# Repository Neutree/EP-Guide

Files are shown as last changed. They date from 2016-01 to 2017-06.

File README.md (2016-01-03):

EP-Guide
=========================
------Easy Parking Guide 智能车库引导系统
-------------------------

# 功能描述

* 可进行车库内车辆的定位(基于RFID)
* 进库时车库会自动寻找最佳位置，用灯光对用户进行引导停车
* 管理员使用web端进行管理
* 用户使用移动app进行查看修改车辆信息、接收提醒、分享信息等
* 家人功能，能够将停车信息贡献给家人，在回家停车时通过app告知家人

###### 管理员专有
* 设置车库布局和传感器布局（画图的方式画出布局，然后将传感器节点（RFID）拖动到相应位置）
* 查看车库内每个车位的停泊信息（是否停泊、如果是可以查看该车位的个人信息）
* 设置车位价格信息
* 设置用户个人信息

###### 用户
* 停车(停车时车库会进行泊车引导，让找车位更简单)
* 查看、修改自己的车辆信息
* 查看自己的车在车库的状态
* 预约车位功能（提前预定车位，保证到达时有车位）
* 家人功能，能够将停车信息贡献给家人，在回家停车时通过app告知家人

# 业务流程图

* 见[流程图](https://github.com/Neutree/EP-Guide/blob/master/Doc/Visio-EP-Guide场景功能流程图.pdf)

# 实现说明

###### 感知控制层
  * MCU：采用stm32f105/107系列
  * 语言：C++
  * 外设：LED、蜂鸣器、RFID阅读器和标签（实验时使用高频，但部署时使用超高频）、wifi模块（esp8266）
  * IDE：Eclipse
  * 电路：Altium Designer

###### 服务器
  * 语言：java
  * IDE：Eclipse
  * 框架：ssh

###### 客户端
* 语言：java
* 系统：Android
* IDE：Android Studio
* 框架模式：MVC
* API：Target:23 Min:15

# 托管地址

[Github->EP-Guide](https://github.com/Neutree/EP-Guide)

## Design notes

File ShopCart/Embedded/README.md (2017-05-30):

[STM32f103 Peripherals Driver Lib](https://github.com/Neutree/STM32f103DriverLib)
======

To make program on STM32 more easier, we packet every peripheral and module as a C++ class, mask operation steps instead of function-oriented interface.

> eg: How to use USART to send data
```cpp
# include "USART.h"
USART com(1,115200);
void main()
{
    com<<"test string\r\n";
}
```

_ _ _
_ _ _
# 如何使用

1. windows上安装keil MDK 5
2. 克隆(推荐)或者下载项目到本地目录,复制一个副本
```
git clone https://github.com/Neutree/STM32f103DriverLib.git
```
3. 打开/template文件夹，该文件夹下面会有相应IDE的工程模板，直接打开运行即可（onchip表示只有STM32片上驱动，offchip表示有一些常用模块的驱动）
4. 需要关心的文件主要在工程的app文件夹下，有三个文件，Main.cpp,Configuration.h,UserInterrupt.cpp.分别为主函数所在、配置使用哪些资源，中断用户程序。
  * 首先检查Configuration.h中需要使用的资源是否取消注释了，不需要使用的资源是否注释了
  * 然后看Main.cpp中硬件定义及其参数,每个外设驱动都有一个文件，具体每个外设驱动的使用请看其头文件。

# 规范
## 文件编码格式
UTF-8 without signature
> keil->edit->configuration->editor->encoding
 
## 目录规范

`lib`：驱动库目录
> `lib/math/`:外设会用到的算法库

> `lib/onchip/`:片上外设驱动
>> `lib/onchip/驱动名`:驱动接口的定义和对驱动的实现

> `lib/offchip/`:片外模块驱动

>> `lib/offchip/驱动名`:驱动接口的定义和对驱动的实现

`example`:驱动库demo，每个驱动一个文件夹,每个芯片一个文件夹
> `example/onchip/驱动名`：具体某个芯片的模块驱动

> `example/offchip/驱动名`：具体某个外围模块驱动

`template`：工程模板，每个IDE或者编译器一个文件夹，下面有特定芯片型号文件夹

`tool`:工具，如删除工程中间文件批处理文件

# 驱动简介

## 片上外设驱动
* **Interrupt**：片上外设中断管理，所有的中断相关的逻辑都在这里
* **GPIO**：通用IO驱动，包括基本IO配置与设置引脚和读取引脚状态
* **USART**：串口驱动，包括了串口1到串口4的驱动，发送可使用DMA，接收使用中断方式，每个串口使用单独的FIFO
* **ADC**：ADC驱动
* **I2C**：I2C驱动，包含了中断方式和DMA方式
* **PWM**：PWM驱动
* **Timer**：定时器驱动
* **TaskManager**：使用systick作为时基，可用来获取系统时间戳、延时（包含软件延时）和定时调用函数
* **Capture**：输入捕获，包括了定时器捕获和外部中断捕获
* **Flash**：STM32内部Flash相关操作，包括对Flash的读写

## 片外模块驱动
* **LED**：基于GPIO和PWM对LED的相关操作，包括开、关、闪烁等
* **esp8266**：esp8266是串口WIFI模块，基于USART对esp8266的相关操作，其中包括了驱动文件（esp8266.cpp）和应用层文件(SockeEsp8266.cpp),应用层文件是使用socket的接口进行通信的实现
* **GPS**：使用USART对GPS模块的驱动
* **HMC5883L**：磁力计，基于I2C通信的HMC5883L的驱动
* **StepMotor**：步进电机驱动，基于GPIO进行控制
* **MPU6050**：6轴惯导驱动，包括了角速度、加速度的读取
* **RemoteControl**:RC遥控器驱动，包含了PWM输入捕获和PPM输入捕获，包括了中断方式和定时器输入捕获方式
* **~~Ultrasonic~~** ~~：超声波驱动，包括了systick版本和定时器版本~~

## 代码风格
看[这里](https://github.com/neutree/simple-code-conventions)

# 贡献者
[AllenWang](https://github.com/afshare)

Danyuanhong

[infiniteYuan](https://github.com/InfiniteYuan1)

[lissettecarlr](https://github.com/lissettecarlr)

[neucrack](http://neucrack.com)

[xz1996](http://git.oschina.net/xz1996)

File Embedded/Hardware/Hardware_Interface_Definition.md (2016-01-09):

硬件外围设备接口定义
=========

# RFID（MFRC522）
* USART2
| 外设引脚名| 引脚编号 |
|---|---|
|TX2(外设RX) | PA2 |
|RX2（外设TX）| PA3 |

* SPI1
| 外设引脚名| 引脚编号 |
|---|---|
|NSS(CSN) | PA4 |
|SCK | PA5 |
|MISO（接收端）（外设MISO）|PA6|
|MOSI（发送端）（外设MOSI）|PA7|

# WIFI
* USART1
| 外设引脚名| 引脚编号 |
|---|---|
|TX1(外设RX) | PA9 |
|RX1（外设TX）| PA10 |

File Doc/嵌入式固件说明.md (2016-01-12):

EP-Guide嵌入式固件说明（V1.5）
=======
# 使用步骤及工作流程说明
1. 车库主控、车位节点、服务安装、部署
2. 开启服务器
3. 管理员现在管理系统（服务器端）进行设置节点数量以及添加MAC地址
4. 主控开机，上电两个灯闪烁一下，然后进行系统初始化、连接wifi等操作，直到交替闪烁表示初始化完毕。<br/>然后双闪表示登录服务器成功，闪4下表示登录服务器失败（如果在后面掉线了也是如此）;红灯双闪表示rfid连接有问题检测到车辆
5. 车位节点开机
6. 主控对所有连接进来了的节点进行轮询，向服务器请求添加节点，添加成功（根据管理员是否将MAC地址加入白名单）后将IP地址与MAC地址进行绑定；如果已经存在了的节点的IP地址有变化，重新设置绑定的IP值
7. 主控定时进行轮询，发现车位状态更改便向服务器报送
8. 当门禁（暂时由主控担任）检测到有车来临时，向服务器请求车位和到达该车位的路径（由车位组成），然后通知节点进行引导（灯光提示），当车在车位（不一定是系统指定的，可以由用户喜好自己选）停下后，主控在轮询中检测到，向服务器报告车位状态的改变，并向节点发送完成引导的消息，然后节点完成引导（灯光恢复正常，绿灯亮表示空闲，红灯亮表示已被占用或者已经被预约）
9. 当汽车离去时，车位检测到状态改变，在主控轮询的时候发送消息给主控，然后主控将消息传递给服务器

# 车库主控
* WIFI为AP+Station模式，作为车库其它节点的AP，同时联网，与服务器交互
  * AP名称：EP-Guide    (WIFI.cpp中可以修改)
  * AP密码：1208077207  (WIFI.cpp中可以修改)
  * AP IP：192.168.4.1                  (WIFI.cpp中可以修改)
  * AP端口：345
  * AP 网关：192.168.4.1  与主控的IP要相同 (WIFI.cpp中可以修改)

  * 作为Station连接的AP名：ICanHearYou
  * 密码：1208077207
  * MAC：12:08:07:72:07:01
* 由于WIFI耗用时间久，RFID扫描（轮询）又对时间要求高，所以要在程序上保证RFID能正确执行
* 对车位节点进行轮询来实现检测车位信息

# 车位节点

* 被动接收主控的轮询
* 既是客户端，也开启TCP服务器，监听来自主控的轮询
* 使用端口号：345 （即节点建立端口号为345的TCP服务）

# 主控与节点之间的通信

#### 节点-->主控
* 节点被动，响应主控的请求

#### 主控-->节点
* 由于主控不知道具体哪个IP对应哪个车位，因此需要将IP与节点MAC绑定
  * 在主控向节点请求状态信息时，在节点返回MAC地址+状态数据后，将IP与MAC进行绑定
* 主控定时向节点请求状态信息

#### 协议
**一）、消息帧定义**

| 传输层 |||| 业务层 |||
|---|---|
| 消息头 | 消息ID | 节点Mac地址 | 消息体长度 | 命令字 | 消息体 | 校验字 |
| gMsgHead | gMsgID | gGtwMac | gMsgLen | bMsgCmd | bMsgBody | bMsgVrf |
| 2Byte | 2Byte | 6Byte | 2Byte | 2Byte | nByte | 1Byte |

**二）、命令字定义**

| 命令编号 | 命令描述 | 命令字 | 命令编码 | 传输方向 |
|---|---|
| 1 | 主控向节点请求状态信息 | cReqStatus | 0x0201 | 主控-节点 |
| 2 | 节点响应主控状态信息请求 | cAckStatus | 0x0901 | 节点-主控 |
| 3 | 主控向节点请求道路引导 | cReqLead | 0x0202 | 主控-节点 |
| 4 | 节点响应主控道路引导请求 | cAckLead | 0x0902 | 节点-主控 |
| 5 | 主控向节点请求完成道路引导 | cReqCompleteLead | 0x0203 | 主控-节点 |
| 6 | 节点响应主控完成道路引导请求 | cAckCompletLead | 0x0903 | 节点-主控 |
| 7 | 主控向节点请求禁用 | cReqDisable | 0x0204  | 主控-节点|
| 8 | 节点响应节点禁用请求 | cAckDisable | 0x0904  | 节点-主控 |

##### 1 状态信息同步到主控
**1.1 主控向节点请求状态消息**
* 消息体
| 内容 |
|--------|
|  是否被预约（1字节）  |
* 1：被预约 0：没被预约

**1.2节点响应状态请求**
* 消息体
| 内容 |
|------|
| 状态信息（1字节） |
| 车辆ID号（4字节） |
* 状态信息定义
| 状态字           | 含义  | 命令编码 |
|--------|--------|                |
| NodeStatus_Busy | 有车  | 0x20    |
| NodeStatus_Free | 空闲  | 0x10    |
| NodeStatus_Disable | 不使用该车位  | 0x08    |
| NodeStatus_ToBusy | 从空闲到有车  | 0x04    |
| NodeStatus_ToFree | 从有车到空闲  | 0x02    |

##### 2 引导道路
**2.1 主控向节点发送引导道路消息**
* 消息体
| 内容 |
|--------|
| 引导角色（1字节）  |
* 角色
| 角色 | 命令编码  |
|---|---|
|  引导 |  0x22 |
|停车车位（终点）| 0x11 |

**2.2 节点对主控引导道路消息的响应**
* 消息体
| 内容 |
|--------|
|  成功？（1字节）  |
* 返回数据定义
| 状态 | 消息编码 |
|---|---|
| 成功 | 1 |
| 失败 | 0 |

**2.3 主控向节点发送完成引导道路消息**
* 消息体
| 内容 |
|--------|
| null  |

**2.4 节点对主控完成引导道路消息的响应**
* 消息体
| 内容 |
|--------|
|  成功？（1字节）  |
* 返回数据定义
| 状态 | 消息编码 |
|---|---|
| 成功 | 1 |
| 失败 | 0 |

##### 3 禁用掉该节点（开机后进行注册，若注册不成功，主控发送禁用消息）

**3.1 主控向节点请求禁用**
* 消息体
| 内容 |
|--------|
|  null |

**3.2 节点向主控响应禁用请求**
* 消息体
| 内容 |
|--------|
|  成功 （1字节）|
* 返回数据定义
| 状态 | 消息编码 |
|---|---|
| 成功 | 1 |

# 主控-->服务器

* 协议见网关与服务器之间通信的协议文档

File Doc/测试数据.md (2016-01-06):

######用户登录
   - url : http://www.doubleeggs.com:8080/EP-Guide/login
   - sendData : {"action":"1001", "username":"dandan","password":"gg"}

{"action":"1001", {"username":"dandan","password":"gg"}}

{
	"resultcode":"200",
	"reason":"SUCCESSED!",
	"error_code":0,
	"result":[
		{
			"citynow":{
				"city":"重庆",
				"AQI":"89",
				"quality":"良",
				"date":"2016-01-05 16:00"
			},

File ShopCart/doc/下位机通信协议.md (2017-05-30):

网关—Server通信协议（Version 1.3）
================
##### 修改记录：
	version 1.0  时间 2016-1-4 新增
    version 1.01 时间 待定

##### 一、协议简介
	网关和服务器之间采用Socket进行通信（Socket是对TCP/IP协议的封装和应用）
	网关-服务端TCP监听端口：5080
	服务器-客户端通信监听端口：8080

##### 二、	报文结构介绍
注:整个通信的报文采用16进制格式

| 传输层 |||| 业务层 |||
|---|---|
| 消息头 | 消息ID | 网关Mac地址 | 消息体长度 | 命令字 | 消息体 | 校验字 |
| gMsgHead | gMsgID | gGtwMac | gMsgLen | bMsgCmd | bMsgBody | bMsgVrf |
| 2Byte | 2Byte | 6Byte | 2Byte | 2Byte | nByte | 1Byte |
**其中需要注意的如下：**

* 消息头固定为：**0xA402**

* 消息ID无符号两字节，递增，网关控制

* 登录时在MAC地址后加 <kbd>A-402</kbd> 字串，然后对其合并后用MD5进行加密

* 高字节在前（先发高字节，再发低字节）

* 消息长度为消息体长度
* 校验字使用和校验 前面所有字节之和对256取余

##### 三、 命令集

| 命令分类 | 命令描述 | 命令字 | 命令编码 | 传输方向 |
|---|---|
| 基本请求 | 登录、心跳包等 |
| 1.1 |网关登录服务器请求 | cReqGateWayLogin | 0x0101 | 网关-Server |
| 1.2 | 服务器响应网关登录 | cAckGateWayLogin | 0x0801 | Server-网关 |
| 1.3 | 链路请求(消息体空) | cReqLinkCheck | 0x0102 | 网关-Server |
| 1.4 | 链路请求响应(消息体空) | cAckLinkCheck | 0x0802 | Server-网关 |
| 标签操作 | 读、写标签数据 |
| 2.1 | 写标签请求 | cReqWriteTag | 0x0104 | Server-网关 |
| 2.2 | 写标签响应 | cAckWriteTag | 0x0804 | 网关-Server |
| 2.3 | 读标签请求 | cReqReadTag | 0x0105 | 网关-Server |
| 2.4 | 读标签响应 | cAckReadTag | 0x0805 | Server-网关 |

##### 四、 消息体定义

**==1.1 登录请求：==**
 - 说明：通过网关Mac地址+A-402 合并后用MD5进行加密
 - 消息体：
   |内容|
   |--------|
   |MD5加密字串（16字节）|

**==1.2 登录响应：==**
 - 说明：1=成功 , 0=失败
 - 消息体：
   |内容|
   |--------|
   |是否成功（2字节）|

**==1.3 链路请求：==**
 - 说明：心跳请求：网关-服务器，间隔30s
 - 消息体：
   |内容|
   |--------|
   |null|

**==1.4 链路请求响应：==**
 - 说明：1=成功 , 0=失败
 - 消息体
   |内容|
   |--------|
   |是否成功（2字节）|

**==2.1 写标签请求：==**
 - 说明：服务器主动发消息到网关，将服务器发送的标签ID写入RFID存储空间中
 - 消息体：
   |内容	  |
   |--------|
   |标签ID（8）|

**==2.2 写标签响应：==**
 - 说明：添加结果-->1=成功 , 0=失败 &nbsp;&nbsp;&nbsp;&nbsp;&nbsp;&nbsp;&nbsp; 
 - 消息体：
   |内容|
   |--------|
   |是否成功（2）|

**==2.3 读标签请求：==**
 - 说明：下位机识别到RFID标签后将信息发到Server
 - 消息体：
   |内容	  |
   |--------|
   |标签个数（2）|           |
   |           |节点ID地址（8） |

**==2.4 读标签响应：==**
 - 说明：是否保存成功-->1：成功 0：失败
 - 消息体：
   |内容|
   |--------|
   |是否成功（2）|

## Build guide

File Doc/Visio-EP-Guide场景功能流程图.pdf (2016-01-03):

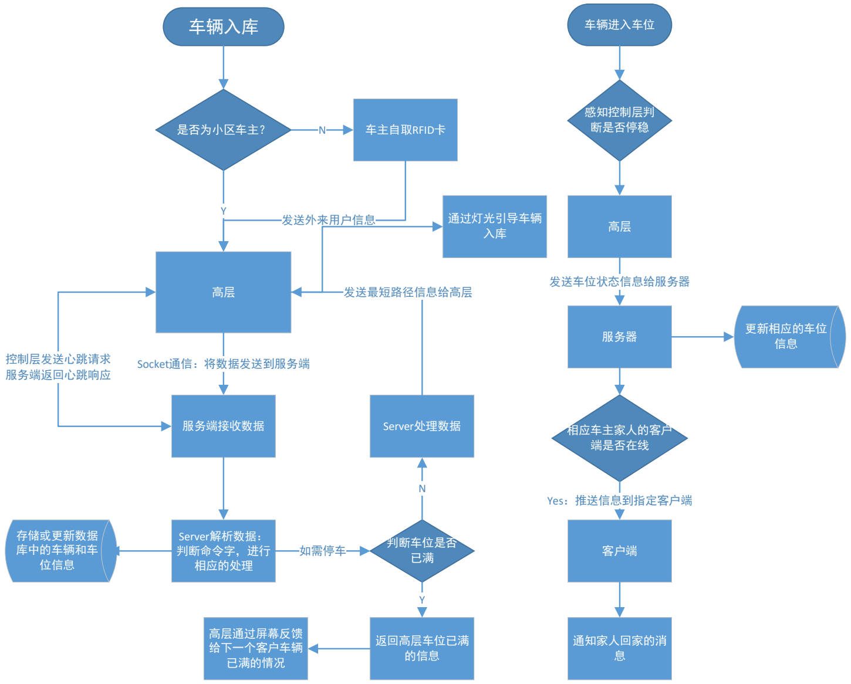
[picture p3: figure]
车辆入库; 是否为小区车主？; 车主自取RFID卡; 服务端接收数据; 控制层发送心跳请求; Socket通信：将数据发送到服务端 服务端返回心跳响应; Server解析数据： 判断命令字，进行 相应的处理; 存储或更新数据 库中的车辆和车 位信息; 判断车位是否 已满 如需停车; Server处理数据; 发送最短路径信息给高层; 发送外来用户信息; 返回高层车位已满 的信息; 高层通过屏幕反馈 给下一个客户车辆 已满的情况; 车辆进入车位; 感知控制层判 断是否停稳; 服务器; 更新相应的车位; 相应车主家人的客户 端是否在线; 客户端; 发送车位状态信息给服务器; Yes：推送信息到指定客户端; 通过灯光引导车辆 入库; 通知家人回家的消 息

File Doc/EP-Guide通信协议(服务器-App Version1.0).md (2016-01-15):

##App—Server通信协议（Version 1.0）

####修改记录：

	version 1.0  时间 2016-1-4 内容：基本协议的制定

    version 1.01 时间 待定 内容： 更新、新增、删除

####一、协议简介

	客户端和服务器之间采用TCP进行通信（客户端只需请求服务器、等待服务器应答）

	客户端请求端口：5090

####二、接口定义

#####用户登录

_ _ _

- 功能：App登录服务器

- 描述：客户端用MD5对密码进行加密，服务器将发来的的密码进行验证，并生成新的token

- 请求地址(url):http://www.doubleeggs.com:8080/EP-Guide/login

- 提交格式：{"action":"1001", "username":"dandan","password":"gg"}

  {"action":"1001","username":"dandan","password":"123456","token":"5200"}

  提交命令字：1001-请求登录

  提交参数：username,password

- 返回格式：{"result":"xxx","token":"xxx"};

  返回命令字：2001-登录失败  4002-密码错误

  6002-账号未注册  8001-登录成功

  返回参数：result,token

- 使用方法：解析JSON对象，先获取result，如果为2001，则data里数据为空

#####用户注册

_ _ _

- 功能：App向服务器进行注册

- 描述：客户端用MD5对密码进行加密，服务器将发来的的密码进行验证，并生成新的token

- 请求地址(url):http://www.doubleeggs.com:8080/EP-Guide/register

- 提交格式：{"action":"1002", "username":"dan","password":"gg","car_ID":"渝B666668"}

  提交命令字：1002-请求注册

  提交参数：username,password,car_ID(车牌号),user_ID(RFID串号,管理员分配)

- 返回格式：{"result":xxx, "data":"{…}"};

  返回命令字：2002-失败 7002-已注册 8002-成功

  返回参数：token

- 使用方法：解析JSON对象，先获取result，如果为2002，则代表注册失败，data里数据为空

#####二次登录(token)

_ _ _

- 功能：App通过本地缓存的token和username向服务器进行登录验证

- 描述：服务器将客户端发来的token与进行验证，如果不通过则强制用户重新登录

- 请求地址(url):http://www.doubleeggs.com:8080/EP-Guide/tokenLogin

- 提交格式：{"action":"1003", "username":"dandan","token":"ad1c0358ae459416e567c3405eb7b963"}

  提交命令字：1003-请求二次登录

  提交参数：username,token

- 返回格式：{"result":xxx, "data":"{…}"};

  返回命令字：2003-失败 6002-账号未注册

  7003-账号异常 8003-成功

  返回参数：null

- 使用方法：解析JSON对象，先获取result，如果为2003，则代表操作失败，7003则代表已有人在其他地方登录过此号，需让用户重新登录，如为8003则登录成功

#####预约停车

_ _ _

- 功能：App向服务器请求各个车位的信息

- 描述：

- 请求地址(url):http://localhost:8080/EP-Guide/queryParkSpaces

- 提交格式：{"action":"1004", "token":"c400f9448fc28b62be1f8ebe13013645","garage_ID":"1"}

  提交命令字：1004-请求车库里所有车位信息

  提交参数：garage_ID,token

- 返回格式：{"result":xxx, "data":"{…}"};

  返回命令字：2004-失败

  　　　　　　3001-非法用户访问,token不正确，需重新登陆

  　　　　　　6004-没有此车库ID

　　　　　　8004-成功

  返回参数：datalist (List<bean>)

  返回格式：{"result":0,"dataList":"[{\"ID\":\"1\",\"garage_ID\":\"1\",\"park_ID\":\"1\",\"park_spaceName\":\"dan\",\"start_time\":123456,\"status\":\"1\"}]"}

- ParkSpace(Bean)构造：String ID,String park_ID, String park_spaceName, String garage_ID, String status, long start_time

- 使用方法：解析JSON对象，先获取result，如果为2004，则代表操作失败，data里数据为空，如果为8004，则返回一个带有List<bean>格式的队列,用Bean来逐个解析list

#####预约车位

_ _ _

- 功能：App向服务器进行请求更改某一个车位的状态信息

- 描述：

- 请求地址(url):http://localhost:8080/EP-Guide/orderParkSpace

- 提交格式：{"action":"1005", "token":"078701c50c5f0fd4395ecd284c645439","garage_ID":"1","car_ID":"1","pSpace_ID":"1"}

  提交命令字：1005-请求更改某一个车位的状态信息（空闲->占用）

  提交参数：garage_ID,pSpace_ID,car_ID,token

- 返回格式：{"result":xxx, "data":"{…}"};

  返回命令字：2005-失败

　　　　　　8800-车位已满

　　　　　　8005-成功

  返回参数：null

- 使用方法：解析JSON对象，先获取result，如果为2004，则代表操作失败，data里数据为空，如果为8004，则返回一个带有hashMap格式的队列,键值对格式为(pSpace_ID,pSpace_status),ID从1开始取值

#####停车记录查询

_ _ _

- 功能：App向服务器请求

- 描述：客户端用MD5对密码进行加密，服务器将发来的的密码进行验证，并生成新的token

- 请求地址(url):http://localhost:8080/EP-Guide/queryParkHistory

- 提交格式：{"action":"1006", "token":"078701c50c5f0fd4395ecd284c645439","car_ID":"1"}

  提交命令字：1006-请求查询停车记录

  提交参数：car_ID,token

- 返回格式：{"result":xxx, "data":"{…}"};

  返回命令字：2006-失败 6006-没有停车记录 8006-成功

  返回参数：park_history (List<Bean>)

  参数说明：

  Bean - parked

	```

	park_ID （停车位ID）

	garage_ID （车库ID）

	getIn_time(入库时间,时间戳,解析为年-月-日-分)

	park_time (停车时长,时间戳，解析为小时)

	```

- 使用方法：解析JSON对象，先获取result，如果为2002，则代表注册失败，data里数据为空,如果为8006，则返回一个停车历史纪录的List,需遍历逐一取出.

#####心跳请求

_ _ _

- 功能：建立客户端与服务器之间的心跳，判断双方是否在线

- 描述：因为Http是一种无状态协议，所有App需定时向服务器发送心跳请求，服务器收到后进行心跳响应，

- 请求地址(url):ep-guide/api/xxx.java

- 提交格式：{"action":xxx, "data":"{...}"};

  提交命令字：1007-请求

  提交参数：

- 返回格式：{"result":xxx, "data":"{…}"};

  返回命令字：2007-失败

　　　　　　8007-成功

　　　　　　9007-成功且有新的消息

  返回参数：Msg_backHome(String)

- 使用方法：解析JSON对象，先获取result，如果为2007，则代表注册失败，返回值为空，如果为8007则表示服务器收到请求，返回值为空，如果9007则表示有家人回家了

#####模板

_ _ _

- 功能：

- 描述：

- 请求地址(url):ep-guide/api/xxx.java

- 提交格式：{"action":xxx, "data":"{...}"};

  提交命令字：100x-请求

  提交参数：

- 返回格式：{"result":xxx, "data":"{…}"};

  返回命令字：200x-失败

　　　　　　800x-成功

  返回参数：

- 使用方法：解析JSON对象，先获取result，如果为2002，则代表注册失败，data里数据为空

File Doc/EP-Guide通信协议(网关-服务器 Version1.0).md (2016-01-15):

网关—Server通信协议（Version 1.3）
================
##### 修改记录：
	version 1.0  时间 2016-1-4 新增
    version 1.01 时间 待定

##### 一、协议简介
	网关和服务器之间采用Socket进行通信（Socket是对TCP/IP协议的封装和应用）
	网关-服务端TCP监听端口：5080
	服务器-客户端通信监听端口：8080

##### 二、	报文结构介绍
注:整个通信的报文采用16进制格式

| 传输层 |||| 业务层 |||
|---|---|
| 消息头 | 消息ID | 网关Mac地址 | 消息体长度 | 命令字 | 消息体 | 校验字 |
| gMsgHead | gMsgID | gGtwMac | gMsgLen | bMsgCmd | bMsgBody | bMsgVrf |
| 2Byte | 2Byte | 6Byte | 2Byte | 2Byte | nByte | 1Byte |
**其中需要注意的如下：**

* 消息头固定为：**0xA402**

* 消息ID无符号两字节，递增，网关控制

* 登录时在MAC地址后加 <kbd>A-402</kbd> 字串，然后对其合并后用MD5进行加密

* 高字节在前（先发高字节，再发低字节）

* 消息长度为消息体长度
* 校验字使用和校验 前面所有字节之和对256取余

##### 三、 命令集

| 命令分类 | 命令描述 | 命令字 | 命令编码 | 传输方向 |
|---|---|
| 基本请求 | 登录、心跳包等 |
| 1.1 |网关登录服务器请求 | cReqGateWayLogin | 0x0101 | 网关-Server |
| 1.2 | 服务器响应网关登录 | cAckGateWayLogin | 0x0801 | Server-网关 |
| 1.3 | 链路请求(消息体空) | cReqLinkCheck | 0x0102 | 网关-Server |
| 1.4 | 链路请求响应(消息体空) | cAckLinkCheck | 0x0802 | Server-网关 |
| 节点操作 | 管理员操作时更改 |
| 2.1 | 节点添加请求 | cReqAddNode | 0x0104 | 网关-Server |
| 2.2 | 节点添加响应 | cAckAddNode | 0x0804 | Server-网关 |
| 2.3 | 节点删除请求 | cReqNodeDel | 0x0105 | 网关-Server |
| 2.4 | 节点删除响应 | cAckNodeDel | 0x0805 | Server-网关 |
| 控制 | 客户端预约车位时控制 |
| 3.1 | 更改车位状态请求 | cReqNodeStatusUpdate | 0x0107 | 网关-Server |
| 3.2 | 更改车位状态响应 | cAckNodeStatusUpdate | 0x0807 | Server-网关 |
| 同步 | 车位状态改变时同步 |
| 4.1 | 节点信息同步通知 | cReqNotNodeInforSync | 0x0108 | 网关-Server |
| 4.2 | 节点信息同步通知响应 | cAckNotNodeInforSync | 0x0808 | Server-网关 |
| 触发模式 | 车辆入库时触发 |
| 5.1 | 最短路线配置请求 | cReqShortLoad | 0x0103 | 网关-Server |
| 5.2 | 最短路线配置响应 | cAckShortLoad | 0x0803 | Server-网关 |

##### 四、 消息体定义

**==1.1 登录请求：==**
 - 说明：通过网关Mac地址+A-402 合并后用MD5进行加密
 - 消息体：
   |内容|
   |--------|
   |MD5加密字串（16字节）|

**==1.2 登录响应：==**
 - 说明：1=成功 , 0=失败
 - 消息体：
   |内容|
   |--------|
   |是否成功（2字节）|

**==1.3 链路请求：==**
 - 说明：心跳请求：网关-服务器，间隔30s
 - 消息体：
   |内容|
   |--------|
   |null|

**==1.4 链路请求响应：==**
 - 说明：1=成功 , 0=失败
 - 消息体
   |内容|
   |--------|
   |是否成功（2字节）|

**==2.1 节点添加请求：==**
 - 说明：添加节点信息，下面检测到新的节点时，向服务器发送添加新的节点请求
 - 消息体：
   |内容	  |
   |--------|
   |节点个数（2）|
   |           |节点MAC地址（6） |

**==2.2 节点添加响应：==**
 - 说明：添加结果-->1=成功 , 0=失败 &nbsp;&nbsp;&nbsp;&nbsp;&nbsp;&nbsp;&nbsp; 车位状态-->0：空闲  1：占用
 - 消息体：
   |内容|
   |--------|
   |是否成功（2）|
   |该节点的初始状态（2）|

**==2.3 节点删除请求：==**
 - 说明：删除某一车位节点
 - 消息体：
   |内容	  |
   |--------|
   |节点个数（2）|           |
   |           |节点MAC地址（6） |

**==2.4 节点删除响应：==**
 - 说明：是否删除成功-->1：成功 0：失败
 - 消息体：
   |内容|
   |--------|
   |是否成功（2）|

**==3.1 更改车位状态请求：==**
 - 说明：车挺进车位后需更改状态信息
 - 消息体：
   |内容	  |
   |--------|
   |节点MAC（6）|
   |节点状态（2）|
   |车主ID（4）|

**==3.2 更改车位状态响应：==**
 - 说明：是否更改成功-->1：成功 0：失败
 - 消息体：
   |内容|
   |--------|
   |是否成功（2）|

**==4.1 节点信息同步通知：==**
 - 说明：网关请求服务是否有车位被预约
 - 消息体：
   |内容	  |
   |--------|
   |空闲节点个数（2）|
   |  节点MAC（6）  |

**==4.2 节点信息同步通知响应：==**
 - 说明：返回已被预约的车位节点ID，返回消息体为null说明没有被预约的
 - 消息体：
   |内容|
   |--------|
   |已预约车位节点个数（2） |
   |节点MAC（6） |

**==5.1 最短路线配置请求：==**
 - 说明：在得知车库有空闲后再发，将所有车位节点的数据同步到服务器，服务器解析并寻找最短路径
 - 消息体：
   |内容	  |
   |--------|
   |节点个数（2）|           |
   |           |节点MAC（6） |
   |           |节点状态（2）|

**==5.2 最短路线配置请求：==**
 - 说明：返回车主需走过的最短车位节点ID队列，最后一个即为要进的车位，如果为null则表示没空闲车位
 - 消息体：
   |内容	  |
   |--------|
   |节点个数（2）|           |
   |           |节点MAC（6） |

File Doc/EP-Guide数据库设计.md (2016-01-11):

##数据库设计

#####用户表(user)
- username (主键) （String）
- password (MD5+SHA1双重加密,初次登录或重新登录验证) （String）
- token (二次登录验证) （String）
- car_ID (车牌号) （String）
- user_ID (RFID串号)

#####车库表(garage)
- garage_ID (主键)
- garage_name (车库名)
- isFull (是否已满)
- gtwMac （网关mac地址）

#####车位表(parking_spaces)
- ID (主键) (int)
- park_ID （停车位ID,节点ID） （String）
- park_spaceName (车位名) （String）
- garage_ID （车库ID） (int)
- status (车位状态,空闲or占用?) (int)
- car_ID (所停车的ID) (String)
- start_time (停车开始时刻) (存时间戳)(long)
- user_ID (RFID串号)

#####历史停车记录表(history_park)
- ID (主键) (int)
- car_ID (String)
- pSpace_ID （停车位ID） （String）
- garage_ID （车库ID） （String）
- getIn_time(入库时间) (存时间戳)(long)
- park_time (停车时长) (存时间戳)(long)

#####网关表(gateway)
- gtwmac (主键) （String）
- password (MD5加密) （String）
- garage_ID (车库ID) （int）

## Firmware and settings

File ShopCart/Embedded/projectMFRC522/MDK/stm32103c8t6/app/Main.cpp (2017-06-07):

#define OFFLINE_RETRY_INTERVAL  10  //s
#define LOGGING_MAX_WAIT_TIME   10  //s
#define SEND_HEARTBEAT_TIME_INTERVAL    60 //s
#define LOGGED_MAX_HEARTBEAT_WAIT_TIME  130 //s
#define MAX_CARD_QUANTITY 10
#define MAX_CARD_NOT_READ_TIME 3  //s




#include "stm32f10x.h"
#include "Configuration.h"
#include "TaskManager.h"
#include "USART.h"
#include "LED.h"
#include "Socket_esp8266.h"
#include "Communicate.h"
#include "SPI.h"
#include "MFRC522.h"



USART com(1,115200);
USART com2(2,115200);
Socket_esp8266 wifi(com2);

GPIO ledRedGPIO(GPIOB,0,GPIO_Mode_Out_PP,GPIO_Speed_50MHz);//LED GPIO
LED ledRed(ledRedGPIO);//LED red

SPI spi1(SPI1);
MFRC522 rfid(&spi1);

Communicate conn(wifi);


/*******************configuration****************/
//char* mApJoinName  ="Neucrack";
//char* mApJoinPasswd="15023490062...";
//char* mServerIP    = "192.168.168.125";
//uint16_t mServerPort  = 5080;

char* mApJoinName  ="LocalServer";
char* mApJoinPasswd="dandancool";
char* mServerIP    = "192.168.191.1";
uint16_t mServerPort  = 5080;

//char* mApJoinName  ="MI 5";
//char* mApJoinPasswd="12345678";
//char* mServerIP    = "192.168.43.229";
//uint16_t mServerPort  = 5080;
/***********************************************/


char dataToSend[10]={1,2,3,4,5,6,7,8,9,10};
uint8_t dataToRead[50];
unsigned char defaultKey[6] = {0xFF, 0xFF, 0xFF, 0xFF, 0xFF, 0xFF};

typedef struct
{
	uint8_t exist;
	uint8_t cardID[8];
	double timestrap;
}cardInfo_t;
cardInfo_t cardInfo[MAX_CARD_QUANTITY];


bool WiFiInit(void);

typedef enum
{
	STATUS_LOGGING_IN=0,
	STATUS_LOGGED_IN=1,
	STATUS_OFFLINE=2,
}status_t;
status_t status;
float offline_time,recv_heartbeat_time,send_heartbeat_time;

/*****************************************************************************/

void StatusCheck();
void RFIDFind();
bool WriteNumber(uint8_t* number);
bool IsCardExist(uint8_t* cardNumber);
void CardAdd(uint8_t* cardNumber);
void FlushTimestrap(uint8_t* cardNumber);
void CardTimeoutCheck();
void SendCardInfo2Server(uint8_t* cardNumber);
uint8_t CardQuantity();


void init()
{
	com<<"start initialize...\n";
	ledRed.Off();
	status = STATUS_OFFLINE;
	offline_time = TaskManager::Time();
	if(!WiFiInit())
	{
		com<<"WiFi init fail\r\n";
		while(1)
			ledRed.Blink(0,100,false);
	}
	ledRed.Blink(6,100,true);
	com<<"start log in!\n";
	conn.Login();
	status = STATUS_LOGGING_IN;
	
	rfid.PCDReset();
	for(uint8_t i=0;i<MAX_CARD_QUANTITY;++i)
		cardInfo[i].exist = 0;
	com<<"card quantity now:"<<CardQuantity()<<"\n";
	com<<"initialize complete!\n";
}
void loop()
{
	if(status == STATUS_OFFLINE)
		ledRed.Blink(0,2000,false);
	else
		ledRed.Blink(0,500,false);

	if(com2.ReceiveBufferSize()>10)
	{
		bool success = false;
		uint16_t length = wifi.Read((char*)dataToRead);
		com <<"received data,length:"<<length<<"\n";
		int16_t cmd = conn.Decode(dataToRead,&length);
		switch(cmd)
		{
			case From_SERVER_cAckLogin:
				if(status == STATUS_LOGGING_IN && dataToRead[0]==0 && dataToRead[1]==1)
				{
					com<<"log in success!\n";
					status = STATUS_LOGGED_IN;
					recv_heartbeat_time = TaskManager::Time();
				}
				break;
			case From_SERVER_cAckLinkCheck:
				if(dataToRead[0]==0 && dataToRead[1]==1)
				{
					com<<"received heartbeat ack!\n";
					recv_heartbeat_time = TaskManager::Time();
				}
				break;
			case From_SERVER_cAckReadTag:
				if(dataToRead[0]==0 && dataToRead[1]==1)
					com<<"send card info success!\n";
				break;
			case From_SERVER_cReqWriteTag:
				com<<"received write ID command!\n";
				success = WriteNumber(dataToRead);
				conn.AckWrite(success);
				com<<"wirite card ID,success?:"<<success<<"\n";
				break;
			default:
				com<<"undefined cmd: "<<cmd<<"\n";
				break;
		}
	}
	RFIDFind();
	CardTimeoutCheck();
	StatusCheck();
}

void StatusCheck()
{
	switch((uint8_t)status)
	{
		case STATUS_OFFLINE:
			if(TaskManager::Time()-offline_time > OFFLINE_RETRY_INTERVAL)
			{
				com<<"start log in!\n";
				wifi.Close();
				if(!wifi.Connect(mServerIP,mServerPort,Socket_Type_Stream,Socket_Protocol_IPV4))
					com<<"fail to connect server!!!\n";
				conn.Login();
				status = STATUS_LOGGING_IN;
			}
			break;
		case STATUS_LOGGING_IN:
			if(TaskManager::Time()-conn.LoginReqTime() > LOGGING_MAX_WAIT_TIME)
			{
				com<<"log in fail! auto try again after "<<OFFLINE_RETRY_INTERVAL<<"s later!\n";
				status = STATUS_OFFLINE;
				offline_time = TaskManager::Time();
			}
			break;
		case STATUS_LOGGED_IN:
			if(TaskManager::Time()-send_heartbeat_time>SEND_HEARTBEAT_TIME_INTERVAL)
			{
					send_heartbeat_time = TaskManager::Time();
					conn.LinkCheck();
			}
			if(TaskManager::Time()-recv_heartbeat_time > LOGGED_MAX_HEARTBEAT_WAIT_TIME)
			{
				com<<"keep heartbeat fail! auto try log in after "<<OFFLINE_RETRY_INTERVAL<<"s later!\n";
				status = STATUS_OFFLINE;
				offline_time = TaskManager::Time(); 
			}
			break;
	}
}

void RFIDFind()
{
	uint8_t mTagInfo[4];
	if(rfid.PcdRequest(MFRC522_PICC_REQIDL,mTagInfo))//寻到卡
	{
		if(((u16)mTagInfo[0]<<8|mTagInfo[1])==MFRC522_PICC_MIFARE_ONE_S50)//卡类型：S50
		{
			if(rfid.PcdAntiColl(mTagInfo))//防冲撞成功(找到一张卡序列号)
			{
				if(rfid.PcdSelect(mTagInfo))//选卡，卡号为前一步找到的卡号
				{	
					if(rfid.PcdAuthState(MFRC522_PICC_AUTHENT1A, 2, defaultKey, mTagInfo))
					{
						uint8_t cardValue[16] = {0};
						if(rfid.PcdRead(2,cardValue))
							if(!IsCardExist(cardValue))
							{
								com<<"find new card! card quantity now:"<<CardQuantity()<<"\n";
								CardAdd(cardValue);
								SendCardInfo2Server(cardValue);
							}
					}
				}
			}
			
		}
	}
}


bool WriteNumber(uint8_t* number)
{
	uint8_t mTagInfo[4];
	if(rfid.PcdRequest(MFRC522_PICC_REQIDL ,mTagInfo))//寻到卡
	{
		if(((u16)mTagInfo[0]<<8|mTagInfo[1])==MFRC522_PICC_MIFARE_ONE_S50)//卡类型：S50
		{
			if(rfid.PcdAntiColl(mTagInfo))//防冲撞成功(找到一张卡序列号)
			{
				if(rfid.PcdSelect(mTagInfo))//选卡，卡号为前一步找到的卡号
				{	
					if(rfid.PcdAuthState(MFRC522_PICC_AUTHENT1A, 2, defaultKey, mTagInfo))
					{
						uint8_t cardValue[16] = {0,0,0,0,0,0,0,0,0,0,0,0,0,0,0,0};
						memcpy(cardValue,number,8);
						rfid.PcdWrite(2,cardValue);
						rfid.PcdHalt();//休眠卡
						return true;
					}
				}
			}
		}
	}
	return false;
}


uint8_t CardQuantity()
{
	uint8_t i=0,quantity=0;
	for(;i<MAX_CARD_QUANTITY;++i)
	{
		if(cardInfo[i].exist == 1)
			++quantity;
	}
	return quantity;
}
bool IsCardExist(uint8_t* cardNumber)
{
	uint8_t i=0;
	for(;i<MAX_CARD_QUANTITY;++i)
	{
		if(cardInfo[i].exist == 1)
		{
			if(memcmp(cardNumber,cardInfo[i].cardID,8)==0)
			{
				//flush timestrap
				cardInfo[i].timestrap = TaskManager::Time();
				return true;
			}
		}
	}
	return false;
}
void CardAdd(uint8_t* cardNumber)
{
	uint8_t i=0;
	for(;i<MAX_CARD_QUANTITY;++i)
	{
		if(cardInfo[i].exist == 0)
		{
			cardInfo[i].exist=1;
			memcpy(cardInfo[i].cardID,cardNumber,8);
			cardInfo[i].timestrap = TaskManager::Time();
			break;
		}
	}
}
void CardTimeoutCheck()
{
	uint8_t i=0;
	for(;i<MAX_CARD_QUANTITY;++i)
	{
		if(cardInfo[i].exist == 1)
		{
			if(TaskManager::Time()-cardInfo[i].timestrap > MAX_CARD_NOT_READ_TIME)//指定时间段内没有读到卡，判定卡离线
			{
				cardInfo[i].exist = 0;
			}
		}
	}
}
void SendCardInfo2Server(uint8_t* cardNumber)
{
 	if(status != STATUS_LOGGED_IN)
		return;
	if(TaskManager::Time()-send_heartbeat_time>SEND_HEARTBEAT_TIME_INTERVAL-2)//即将发送心跳数据，防止心跳数据和读卡信息一起发送（主要是服务器处理有问题会粘包）
		send_heartbeat_time+=3;
	else if(TaskManager::Time() - send_heartbeat_time <2)//刚刚发了心跳
		TaskManager::DelayS(1);
	static float last_send_time=TaskManager::Time();	
	if(TaskManager::Time() - last_send_time<3)
		TaskManager::DelayS(2);
	conn.SendCardID(1,cardNumber);
	last_send_time = TaskManager::Time();
}


/****************************************************************************/




bool WiFiInit()
{
		com<<"setting wifi...\n";
    wifi.Init();//初始化时一定要清除串口缓冲区，因为WiFi上电后回显很多调试信息，可能会造成串口缓冲区溢出，上电大于2秒后调用
    if(!wifi.Kick())
        return false;
    wifi.SetEcho(false);//关闭回响
    wifi.SetMode(esp8266::esp8266_MODE_STATION,esp8266::esp8266_PATTERN_DEF);//设置为station模式
    wifi.SetMUX(false);//单连接模式
		com<<"WiFi join AP now....\n";
    if(!wifi.JoinAP(mApJoinName,mApJoinPasswd,esp8266::esp8266_PATTERN_DEF))//加入AP
		{
			com<<"join WiFi AP fail!!\n";
			return false;
		}
    TaskManager::DelayS(2);
		com<<"WiFi join suceess!\n";
    //连接服务器
    if(!wifi.Connect(mServerIP,mServerPort,Socket_Type_Stream,Socket_Protocol_IPV4))
        return false;
    return true;
}



int main()
{
	ledRed.On();
	TaskManager::DelayS(3);
	ledRed.Blink(4,100,true);
	ledRed.Off();
	init();
	while(1)
	{
		loop();
	}
}

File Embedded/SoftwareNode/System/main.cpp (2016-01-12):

# include "App.h"

int main()
{
	app.InitHardware();
	app.InitSoft();
	while(1)
	{
		app.Loop();
	}
}










/*
# include "USART.h"
# include "MFRC522.h"
# include "GPIO.h"

*//*GPIO rfidResetPin(GPIOA,0,GPIO_Mode_Out_PP,GPIO_Speed_50MHz);*//*
GPIO ledGreen(GPIOB,1,GPIO_Mode_Out_PP,GPIO_Speed_50MHz);
GPIO ledRed(GPIOB,0,GPIO_Mode_Out_PP,GPIO_Speed_50MHz);
USART com1(1,115200,true);
USART com2(2,9600,true);


MFRC522 rfid1(&com2);

//PICC默认密码(6个字节均为0xff)
const unsigned char DefaultKey[6] = {0xFF, 0xFF, 0xFF, 0xFF, 0xFF, 0xFF};
const unsigned char data1[16] = {0,1,2,3,4,5,6,7,8,9,10,11,12,13,14,15};
unsigned char tagInfo[MFRC522_MaxReceiveLen];
u8 temp[20];
int main()
{
	//关两个LED
	ledRed.SetLevel(1);
	ledGreen.SetLevel(1);
	ledRed.SetLevel(0);
	TaskManager::DelayS(1);
	ledGreen.SetLevel(0);
	//PCD复位
	rfid1.PCDReset();
	com1<<"start\n\n\n";
	u8 temp1=(0x37<<1)|0x80,temp2;
	while(1)
	{
		TaskManager::DelayMs(300);
//		if(spi1.ReadOrWriteByte(temp1,&temp2))
//			com1<<"send ok\t"<<temp1<<"\t"<<temp2<<"\n";
//		else
//			com1<<"send failed\n";
//		++temp1;
	
		if(temp1==0x37)
			temp1=0x38;
		else
			temp1=0x37;
		temp2=rfid1.ReadRawRC(temp1);
		com1<<temp1<<"\t"<<temp2<<"\n";
		temp2=11;
		com1<<temp2<<"\n\n\n";
		
		if(rfid1.WriteRawRC(0x02,9))
			com1<<"write ok\n";
		else
			com1<<"write fail\n";
		com1<<"value: "<<rfid1.ReadRawRC(2)<<"\n\n\n\n\n\n";
		
		temp2=11;
		
		if(rfid1.PcdRequest(MFRC522_PICC_REQALL,tagInfo))//寻到卡
		{
			//com1.SendData(tagInfo,2);//显示卡类型
			if(((u16)tagInfo[0]<<8|tagInfo[1])==MFRC522_PICC_MIFARE_ONE_S50)
				com1<<"\nMIFARE-M1-S50 card detected!\n";
			ledGreen.SetLevel(0);
			if(rfid1.PcdAntiColl(tagInfo))//防冲撞成功(找到一张卡序列号)
			{
				//显示ID
				com1<<"Card ID:\t";
				for(int i=0;i<4;++i)
					com1<<tagInfo[i]<<"\t";
				com1<<"\n";
				
				if(rfid1.PcdSelect(tagInfo))//选卡，卡号为前一步找到的卡号
				{
					
					if(rfid1.PcdAuthState(MFRC522_PICC_AUTHENT1A,1,(unsigned char*)DefaultKey,tagInfo))//校验A密匙
					{
						if(rfid1.PcdWrite(1,(u8*)data1))//向块1写入数据data1
						{
							
							if(rfid1.PcdRead(1,tagInfo))
							{
								com1<<"Read success,Data:\n";
								for(u8 i=0;i<16;++i)
									com1<<tagInfo[i]<<"\t";
								com1<<"\n";
								com1.SendData(tagInfo,16);//显示读出的块1的数据
								if(rfid1.PcdHalt())
									ledRed.SetLevel(0);//点亮黄灯
								else
									ledRed.SetLevel(1);//熄灭黄灯

							}
						}
						
					}
					
				}
				
			}
			
		}
		else
		{
			ledGreen.SetLevel(1);
			ledRed.SetLevel(1);
			com1<<"find failed!\n";
		}

	}
}

*/

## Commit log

2016-01-04 网关-Server通信协议1.0
2016-01-04 数据库设计,App-server通信协议
2016-01-05 用户登录,测试数据
2016-01-06 二次登录
2016-01-06 ### add SPI driver
2016-01-06 ### update SPI driver
2016-01-06 ### add SPI wat for MFRC522 (not test yet)
2016-01-07 搞定接口查询车库信息 提高Login的健壮性
2016-01-07 ### hardware scheme doc
    [EP-GUIDE-Board.SchDoc, EP-GUIDE-Board2.SchDoc, EP-GUIDE.PrjPcb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]
2016-01-07 停车预约
2016-01-07 ### can read by spi but reamain can not read MFRC522
    [EP-GUIDE-Board2.SchDoc, EP-GUIDE.PrjPcb]
2016-01-07 ### MFRC522 can read write register by SPI but can't request remain
2016-01-07 ### by spi final give up....
2016-01-08 ### give up SPI way
2016-01-08 socket demo
2016-01-08 ##hardware is no bug now, master and node
    [App.cpp, main.cpp]
2016-01-08 ### add LED lib and app framwork
2016-01-09 socket封装
2016-01-09 完善协议 网关-Server
2016-01-11 over 未测试
2016-01-11 #### add led blink for led driver
2016-01-12 ### replace node project with master project
    [App.cpp, main.cpp]
2016-01-14 最终gg版
2017-05-30 add shopcart embeded programs
    [Configuration.h]
